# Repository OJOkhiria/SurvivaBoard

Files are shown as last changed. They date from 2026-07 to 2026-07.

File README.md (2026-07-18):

# SurvivaBoard
A custom LoRa board equipped with an ESP32-S3-WROOM-1-N16R8, Ebyte E22-900M22S SX1262 radio, U.FL antenna, U-BLOX MAX M10S 00B GPS module, MMC5983MA magnetometer, BME688 environmental sensor, and a CR2013-MI2120 display driven by an ILI9341 controller. **DISCLAIMER: AI was lightly used to ensure best practices were followed and to speed up research on parts.**

View demos here!: https://drive.google.com/drive/folders/1J8KjE548HSbNNH2rjGCe2-w3qN4_1LWy?dmr=1&ec=wgc-drive-%5Bmodule%5D-goto 

(drive is currently empty because board isn't built yet)

You can view the PCB on your own with https://kicanvas.org/

# Power
Because the board uses a variety of sensors, a GPS, a radio, and other noisy components, I created two separate 3.3V power rails for devices with different noise tolerances. 5V power first comes in from the USB-C receptacle and is stepped down with a fixed-output 3.3V buck converter (ap63203wu-7). To avoid surging, there are TVS diodes on the USB power lines and the D+/D- data lines, and a polyfuse on the power line immediately before the buck converter. The raw output from the buck converter will be used for the ESP32, Ebyte E22-900M22S, and ILI9341. This output also goes through a ferrite bead and an LDO (tlv75533pdrvr) converter to further reduce noise for sensors and other peripherals.

# Subsystems
**ESP32-S3-WROOM-1-N16R8:** Serves as the controller for the entire board. Has a built-in antenna for WiFi and Bluetooth interfacing and communicates with the other various subsystems with UART, SPI, and I²C. It's equipped with an external reset button and plenty of bulk decoupling using 0.1μF and 10μF capacitors.

**U-Blox MAX M10S 00B:** A GPS/GNSS module that will be used to gather data on the board's location and communicate with the ESP32 via UART. Equipped with a TPD1E05U06DPY ESD protection diode; 10μF, 1μF, and 0.1μF decoupling capacitors; and an external coax connector for an active patch antenna (the Quectel YCGO011AA). 

**Ebyte E22-900M22S:** A LoRa module built on the SX1262 transceiver. Originally, I was going to use a bare SX1262, but I chose to go with the Ebyte module to avoid having to build an entire RF front end from scratch. Has an onboard coax connector for an antenna, which will be connected to the FXP290.07.0100A. Communicates with the ESP32 via SPI, and may be used for Meshtastic integration.

**MMC5983MA:** The magnetometer of the board. It will provide heading information to provide the board with a built-in compass. Communicates with the ESP32 using I²C, and has 1μF and 10μF decoupling capacitors.

**BME688:** An environmental sensor that measures temperature, humidity, barometric pressure, and VOC gases. It can generate IAQ (indoor air quality) and also has integrated artificial intelligence, which will be trained to recognize certain odors/gas signatures. Has 0.1μF and 1μF decoupling capacitors and communicates with the ESP32 using I²C.

**ILI9341:** This will be used to display all the information the board gathers, and potentially for users to use Meshtastic. Has an SD card interface for any fonts or other things, and a PWM backlight control. Has 0.1μF and 10μF decoupling capacitors and communicates with the ESP32 using SPI.

# PCB Design
I went with an 80mm by 120mm rectangular 4-layer with 5mm radius filleted edges, with the following designations:
* Layer 1: Signals and USB power processing
* Layer 2: Solid ground plane (with some unfilled areas for antenna clearance)
* Layer 3: Bulk power distribution
* Layer 4: Extra signals

The subsystems are separated and clustered with their respective components to shorten routes and minimize noise interference, and some of these areas are demarcated with stitching vias. The display sits at the head of the board with the Ebyte module, I²C sensors, and a logo immediately underneath. Near the equator and to the left of the board sits the ESP32, with the antenna facing the board's edge and ~9mm of copper-free clearance on both sides of the antenna. On the right is a 25x25mm copper-free clearance zone to (hopefully) mount the Quectel YCGO011AA. In the bottom left is the MAX M10S with a U.FL coax connector, and in the bottom right is the USB-C receptacle and the power systems.

# Bill of Materials

|Reference|Qty|Value|DNP|Exclude from BOM|Exclude from Board|Footprint|Datasheet|
|---|---|---|---|---|---|---|---|
|AE1|1|Antenna| | | | | |
|C6,C9,C12,C15,C19,C23,C25,C27,C29 | 9 | 0.1uF | | | |Capacitor_SMD:C_0603_1608Metric_Pad1.08x0.95mm_HandSolder|
|C7,C13,C22,C26,C28,C30 | 6 | 10uF | | | |Capacitor_SMD:C_0805_2012Metric_Pad1.18x1.45mm_HandSolder| |
|C10,C11 | 2 | 22uF | | | | Capacitor_SMD:C_1206_3216Metric_Pad1.33x1.80mm_HandSolder | |
|C14 | 1 | 2.2uF | | | | Capacitor_SMD:C_0603_1608Metric_Pad1.08x0.95mm_HandSolder | |
|C16,C18,C20 | 3 | 1uF | | | |Capacitor_SMD:C_0603_1608Metric_Pad1.08x0.95mm_HandSolder | |
|C21 | 1 | 47pF | | | | Capacitor_SMD:C_0603_1608Metric_Pad1.08x0.95mm_HandSolder | |
|C24 | 1 | 4.7uF | | | | Capacitor_SMD:C_0603_1608Metric_Pad1.08x0.95mm_HandSolder | |
| D1 | 1 | D_TVS | | | | Diode_SMD:D_SOD-123F| |
|F1 | 1 | Polyfuse | | | | Fuse:Fuse_2920_7451Metric_Pad2.10x5.45mm_HandSolder | |
|FB1 | 1 | FerriteBead | | | | Ferrite_SMD:BEADC1608X95N | |
|IC1 | 1 | E22-900M22S | | | | ebyte:E22-900M22S | |
| J1 | 1 | USB_C_Receptacle_USB2.0_14P | | | | Connector_USB:USB_C_Receptacle_GCT_USB4105-xxA_16P_TopMnt_Horizontal | https://www.usb.org/sites/default/files/documents/usb_type-c.zip|
| J2 | 1 | Conn_Coaxial | | | | Connector_Coaxial:U.FL_Hirose_U.FL-R-SMT-1_Vertical | |
| L2 | 1 | 3.9uH | | | | Inductor_SMD:L_Sunlord_MWSA0402S | |
| L3 | 1 | 27nH | | | | Inductor_SMD:L_0603_1608Metric_Pad1.05x0.95mm_HandSolder | |
| R1,R2 | 2 | 5.1k | | | | Resistor_SMD:R_0603_1608Metric_Pad0.98x0.95mm_HandSolder | |
| R3,R4 | 2 | 4.7k | | | | Resistor_SMD:R_0603_1608Metric_Pad0.98x0.95mm_HandSolder | |
| R5 | 1 | 10k | | | | Resistor_SMD:R_0603_1608Metric_Pad0.98x0.95mm_HandSolder | |
| SW1 | 1 | SW_Push | | | | Tactile_Switch:SW_TS04-66-55-BK-160-SMT | |
| U1 | 1 | ESP32-S3-WROOM-1 | | | | ESP32-S3-WROOM-1-N16R8:ESP32S3WROOM1N8R2 | https://www.espressif.com/sites/default/files/documentation/esp32-s3-wroom-1_wroom-1u_datasheet_en.pdf|
| U2 | 1 | TPD2EUSB30A | | | | USB_ESD:SOTFL35P100X50-3N |http://www.ti.com/lit/ds/symlink/tpd2eusb30a.pdf|
| U3 | 1 | AP63203WU | | | | Buck_Converter:SOIC_05WU-7_DIO-M |https://www.diodes.com/assets/Datasheets/AP63200-AP63201-AP63203-AP63205.pdf|
| U5 | 1 | MAX-M10S | | | | U-BLOX MAX-M10S:XCVR_MAX-M10S-00B | https://content.u-blox.com/sites/default/files/MAX-M10S_DataSheet_UBX-20035208.pdf|
| U6 | 1 | MMC5983MA | | | | MMC5983MA:MMC5983MA_MEM | |
| U7 | 1 | BME688 | | | | BME688:IC_BME688 | |
| U8 | 1 | TLV75533PDRV | | | | LDO:SOT95P280X145-5N |http://www.ti.com/lit/ds/symlink/tlv755p.pdf|
| U9 | 1 | TPD1E05U06DPY | | | | GPS_ESD:DIO_TPD1E05U06DPYR | https://www.ti.com/lit/ds/symlink/tpd1e05u06.pdf|
| U10 | 1 | CR2013-MI2120 | | | | ILI9341:CR2013-MI2120 | http://pan.baidu.com/s/11Y990|

Screenshot 2026-07-08 at 11 11 59 PM

Screenshot 2026-07-11 at 3 25 43 PM

Screenshot 2026-07-09 at 12 09 27 AM

Screenshot 2026-07-13 at 2 32 15 PM

Screenshot 2026-07-13 at 2 34 44 PM

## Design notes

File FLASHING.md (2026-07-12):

# Flashing SurvivaBoard

The project targets an ESP32-S3-WROOM-1-N16R8 with 16 MB of flash. Firmware
logs use USB Serial/JTAG so UART0 remains available to the MAX-M10S GNSS module.

## Build

```sh
pio run
```

The resulting artifacts are written to:

```text
.pio/build/esp32-s3-devkitc-1-n16r8v/
```

## Flash

Connect the board's USB-C port, then run:

```sh
pio run --target upload
```

If PlatformIO cannot select the serial device automatically, pass the port:

```sh
pio run --target upload --upload-port /dev/cu.usbmodemXXXX
```

On first bring-up, hold the ESP32 boot strap low while resetting the module if
the ROM bootloader does not enter download mode automatically.

The current schematic does not expose GPIO0 as a dedicated BOOT button or test
pad. If the first upload does not start automatically, temporarily pull the
ESP32-S3 module's GPIO0 pad to GND while resetting EN. Add an accessible BOOT
test pad or button in the next PCB revision.

## Monitor

```sh
pio device monitor --baud 115200
```

Expected initial logs report the shared bus bring-up and the availability of
the ILI9341 interface, E22 radio interface, MAX-M10S UART, BME688, and
MMC5983MA.

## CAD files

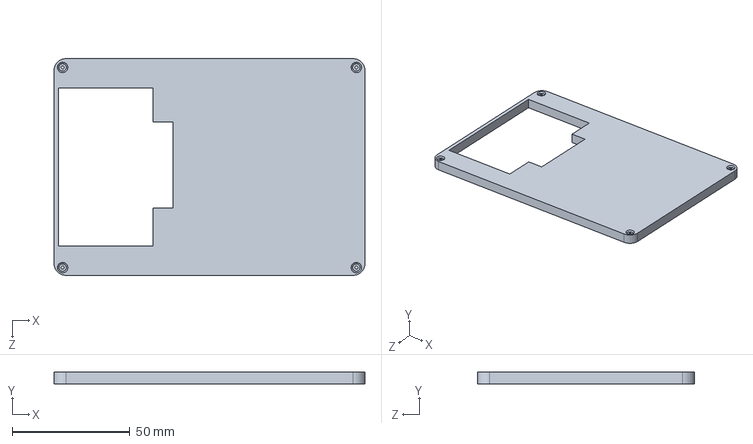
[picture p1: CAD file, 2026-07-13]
CAD Files/SurvivaBoard Case(2).SLDPRT
132.0 x 5.00 x 92.0 mm

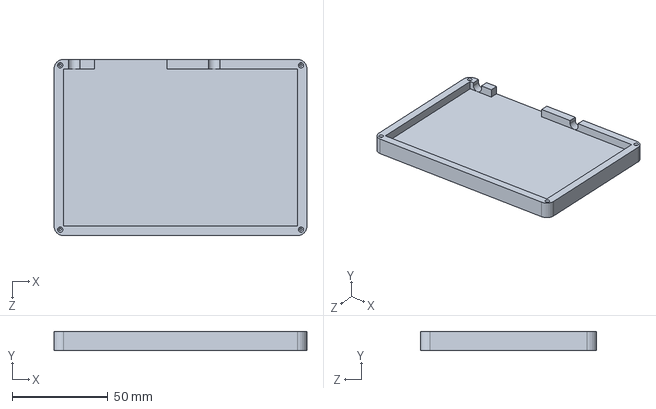
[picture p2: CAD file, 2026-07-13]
CAD Files/SurvivaBoard Case(1).SLDPRT
132.0 x 10.0 x 92.0 mm

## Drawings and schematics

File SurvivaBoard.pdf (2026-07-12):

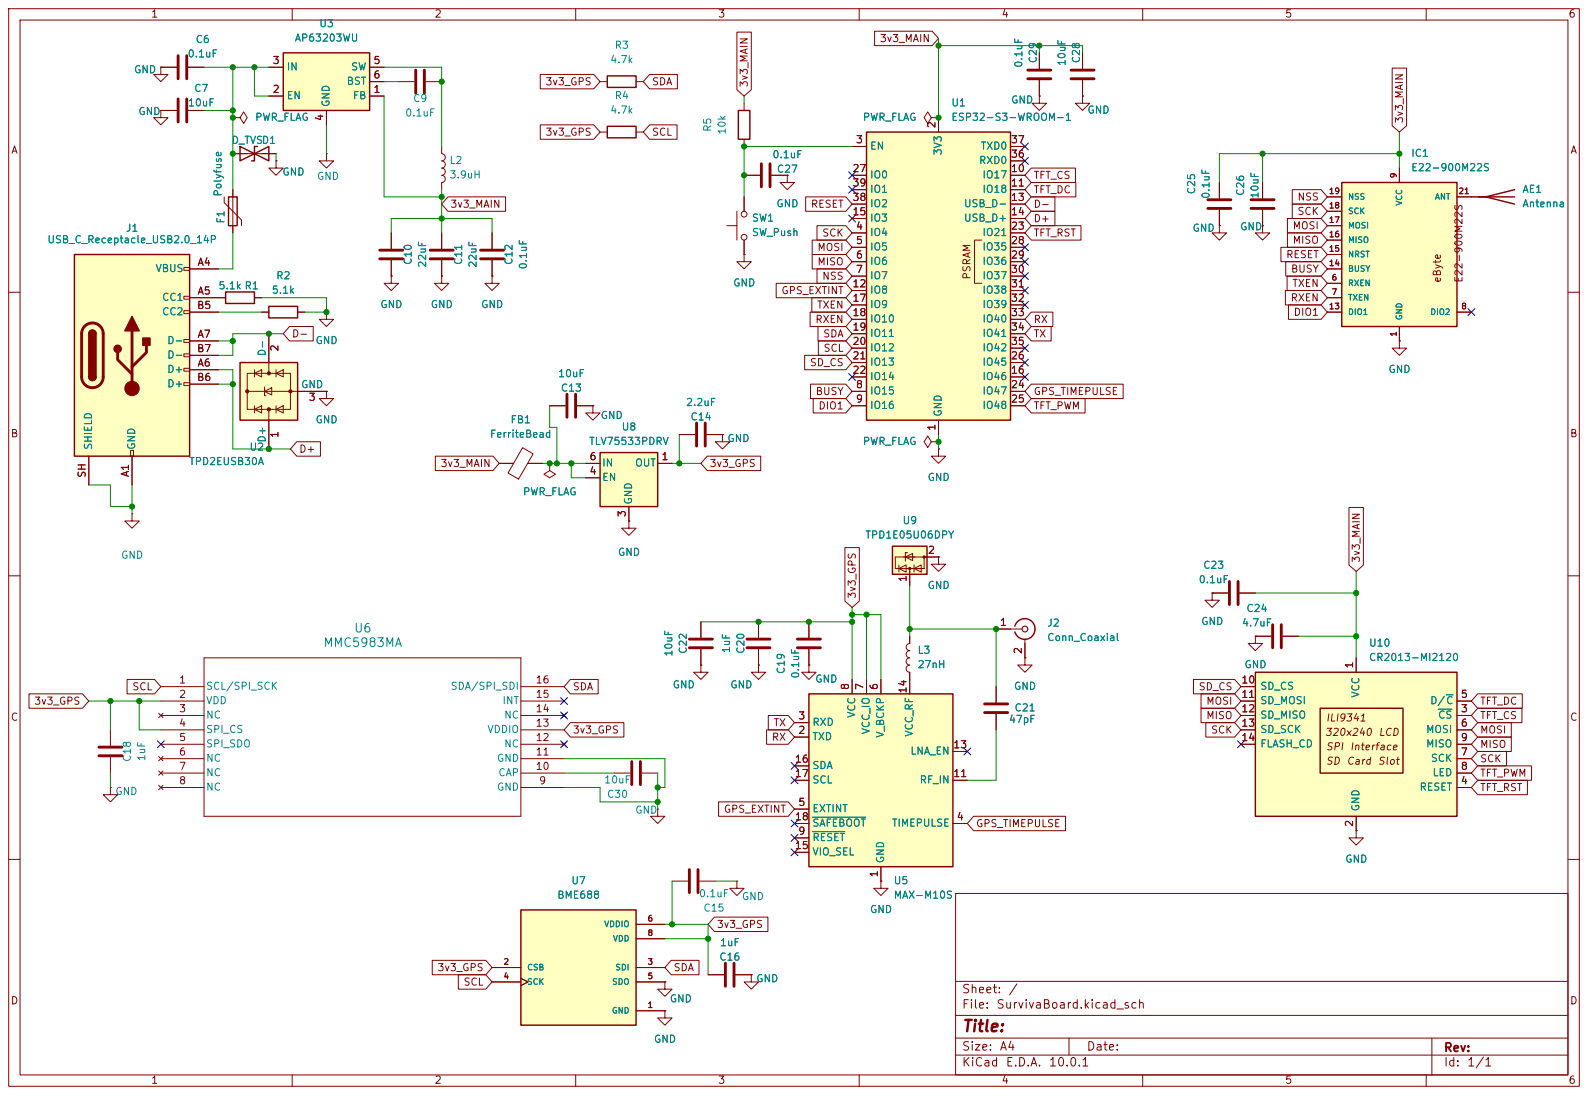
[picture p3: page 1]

9 DIO1 13 BUSY 14 NRST 15 MISO 16 MOSI 17

1 GND
SPI Interface SD Card Slot 320x240 LCD VCC

Size: A4 | Rev:
KiCad E.D.A. 10.0.1 | Id: 1/1

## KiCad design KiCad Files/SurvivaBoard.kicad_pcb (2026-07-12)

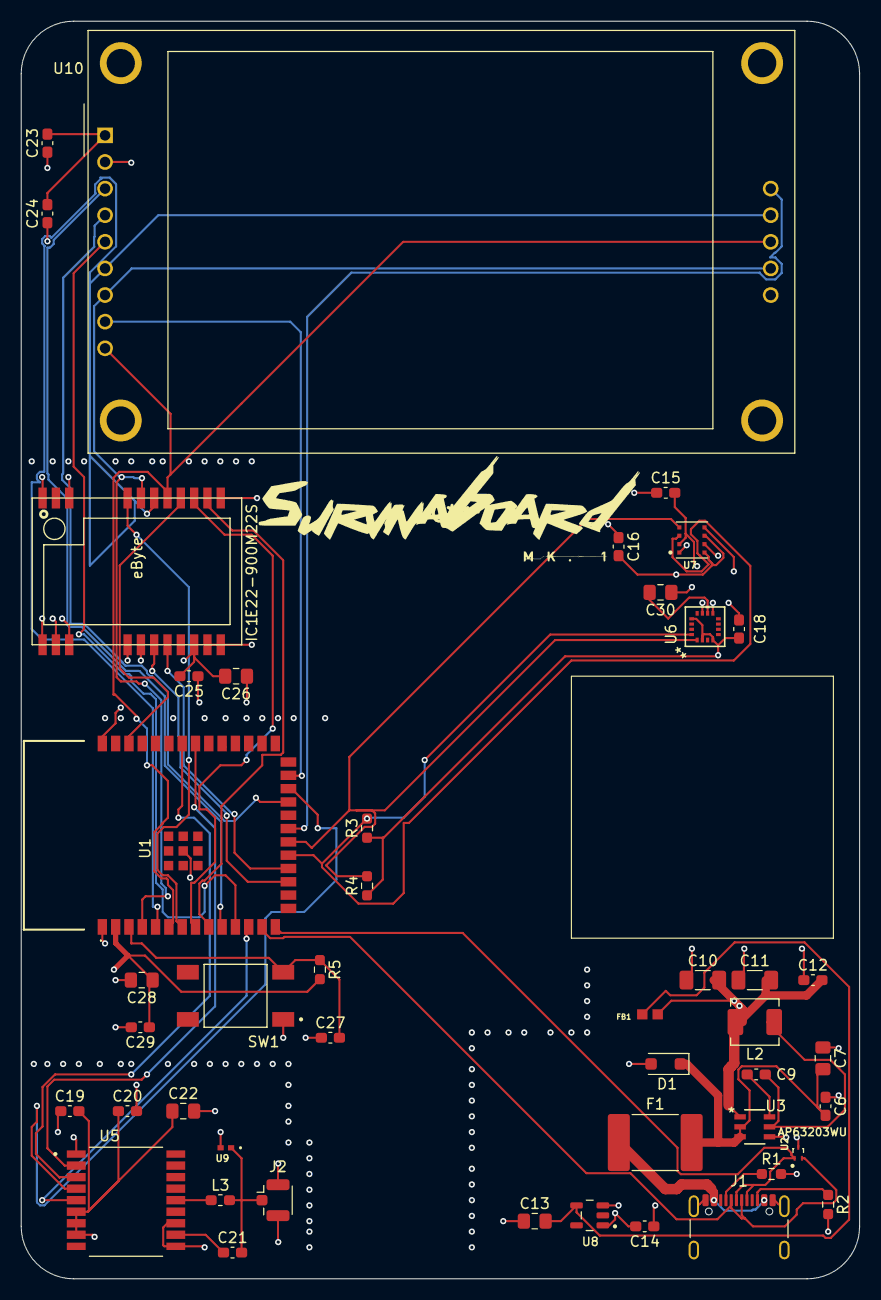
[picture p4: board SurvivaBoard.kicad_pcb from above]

Board: 4 copper layers, 80.0 x 120.0 mm, 46 parts (0 on the bottom side), 37 nets.

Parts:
C6, C9, C12, C15, C19, C23, C25, C27, C29: 0.1uF; C_0603_1608Metric_Pad1.08x0.95mm_HandSolder
C7, C13, C22, C26, C28, C30: 10uF; C_0805_2012Metric_Pad1.18x1.45mm_HandSolder
C10, C11: 22uF; C_1206_3216Metric_Pad1.33x1.80mm_HandSolder
C14: 2.2uF; C_0603_1608Metric_Pad1.08x0.95mm_HandSolder
C16, C18, C20: 1uF; C_0603_1608Metric_Pad1.08x0.95mm_HandSolder
C21: 47pF; C_0603_1608Metric_Pad1.08x0.95mm_HandSolder
C24: 4.7uF; C_0603_1608Metric_Pad1.08x0.95mm_HandSolder
D1: D_TVS; D_SOD-123F
F1: Polyfuse; Fuse_2920_7451Metric_Pad2.10x5.45mm_HandSolder
FB1: FerriteBead; BEADC1608X95N
IC1: E22-900M22S
J1: USB_C_Receptacle_USB2.0_14P; USB_C_Receptacle_GCT_USB4105-xx-A_16P_TopMnt_Horizontal
J2: Conn_Coaxial; U.FL_Hirose_U.FL-R-SMT-1_Vertical
L2: 3.9uH; L_Sunlord_MWSA0402S
L3: 27nH; L_0603_1608Metric_Pad1.05x0.95mm_HandSolder
R1, R2: 5.1k; R_0603_1608Metric_Pad0.98x0.95mm_HandSolder
R3, R4: 4.7k; R_0603_1608Metric_Pad0.98x0.95mm_HandSolder
R5: 10k; R_0603_1608Metric_Pad0.98x0.95mm_HandSolder
SW1: SW_Push; SW_TS04-66-55-BK-160-SMT
U1: ESP32-S3-WROOM-1; ESP32S3WROOM1N8R2
U2: TPD2EUSB30A; SOTFL35P100X50-3N
U3: AP63203WU; SOIC_05WU-7_DIO-M
U5: MAX-M10S; XCVR_MAX-M10S-00B
U6: MMC5983MA; MMC5983MA_MEM
U7: BME688; IC_BME688
U8: TLV75533PDRV; SOT95P280X145-5N
U9: TPD1E05U06DPY; DIO_TPD1E05U06DPYR
U10: CR2013-MI2120

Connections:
3v3_GPS: C14.2, C15.2, C16.2, C18.2, C19.2, C20.1, C22.1, R3.1, R4.1, U5.6 (V_BCKP), U5.7 (VCC_IO), U5.8 (VCC), U6.2 (VDD), U6.4 (SPI_CS), U6.13 (VDDIO), U7.2 (CSB), U7.6 (VDDIO), U7.8 (VDD), U8.1 (OUT)
3v3_MAIN: C10.2, C11.2, C12.2, C23.2, C24.2, C25.2, C26.2, C28.1, C29.1, FB1.1, IC1.9 (VCC), L2.2, R5.2, U1.2 (3V3), U3.1 (FB), U10.1 (VCC)
BUSY: IC1.14 (BUSY), U1.8 (IO15)
D+: J1.A6 (D+), J1.B6 (D+), U1.14 (USB_D+), U2.1 (D+)
D-: J1.A7 (D-), J1.B7 (D-), U1.13 (USB_D-), U2.2 (D-)
DIO1: IC1.13 (DIO1), U1.9 (IO16)
GND: C6.1, C7.1, C10.1, C11.1, C12.1, C13.1, C14.1, C15.1, C16.1, C18.1, C19.1, C20.2, C22.2, C23.1, C24.1, C25.1, C26.1, C27.1, C28.2, C29.2, C30.1, D1.2 (A2), IC1.1 (GND), IC1.2 (GND), IC1.3 (GND), IC1.4 (GND), IC1.5 (GND), IC1.10 (GND), IC1.11 (GND), IC1.12 (GND), IC1.20 (GND), IC1.22 (GND), J1.A1 (GND), J1.A12 (GND), J1.B1 (GND), J1.B12 (GND), J1.SH (SHIELD), J2.2 (Ext), R1.2, R2.2, SW1.1, U1.1 (GND), U1.40 (GND), U1.41 (GND), U2.3 (GND), U3.4 (GND), U5.1 (GND), U5.10 (GND), U5.12 (GND), U6.9 (GND), U6.11 (GND), U7.1 (GND), U7.5 (SDO), U7.7 (GND), U8.3 (GND), U9.2 (GND), U10.2 (GND)
GPS_EXTINT: U1.12 (IO8), U5.5 (EXTINT)
GPS_TIMEPULSE: U1.24 (IO47), U5.4 (TIMEPULSE)
MISO: IC1.16 (MISO), U1.6 (IO6), U10.9 (MISO), U10.12 (SD_MISO)
MOSI: IC1.17 (MOSI), U1.5 (IO5), U10.6 (MOSI), U10.11 (SD_MOSI)
NSS: IC1.19 (NSS), U1.7 (IO7)
unnamed: C6.2, C7.2, D1.1 (A1), F1.2, U3.2 (EN), U3.3 (IN)
unnamed: F1.1, J1.A4 (VBUS), J1.A9 (VBUS), J1.B4 (VBUS), J1.B9 (VBUS)
unnamed: J1.A5 (CC1), R1.1
unnamed: J1.B5 (CC2), R2.1
unnamed: C21.2, J2.1 (In), L3.2, U9.1 (I/O)
unnamed: C27.2, R5.1, SW1.2, U1.3 (EN)
unnamed: C9.1, U3.6 (BST)
unnamed: C9.2, L2.1, U3.5 (SW)
unnamed: C21.1, U5.11 (RF_IN)
unnamed: L3.1, U5.14 (VCC_RF)
unnamed: C30.2, U6.10 (CAP)
unnamed: C13.2, FB1.2, U8.4 (EN)
RESET: IC1.15 (NRST), U1.38 (IO2)
RX: U1.33 (IO40), U5.2 (TXD)
RXEN: IC1.7 (TXEN), U1.18 (IO10)
SCK: IC1.18 (SCK), U1.4 (IO4), U10.7 (SCK), U10.13 (SD_SCK)
SCL: R4.2, U1.20 (IO12), U6.1 (SCL/SPI_SCK), U7.4 (SCK)
SDA: R3.2, U1.19 (IO11), U6.16 (SDA/SPI_SDI), U7.3 (SDI)
SD_CS: U1.21 (IO13), U10.10 (SD_CS)
TFT_CS: U1.10 (IO17), U10.3 (~CS)
TFT_DC: U1.11 (IO18), U10.5 (D/~C)
TFT_PWM: U1.25 (IO48), U10.8 (LED)
TFT_RST: U1.23 (IO21), U10.4 (RESET)
TX: U1.34 (IO41), U5.3 (RXD)
TXEN: IC1.6 (RXEN), U1.17 (IO9)

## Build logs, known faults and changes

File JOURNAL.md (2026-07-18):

# 1
In this session, I worked on the full power system for SurvivaBoard. Because the board uses a variety of sensors, a GPS, a radio, and other noisy components, I created two separate 3.3V power rails for devices with different noise tolerances. 5V power first comes in from the USB-C receptacle and is stepped down with a fixed-output 3.3V buck converter. The raw output from the buck converter will be used for the ESP32, SX1262, and TFT display. This output also goes through a ferrite bead and an LDO converter to further reduce noise for sensors and other peripherals.



# 2
In this session, I wired all the subsystems for SurvivaBoard and tweaked my power system a bit. In summary, I:

- Added a polyfuse and TVS diode to my USB power system to avoid surging
- Added an ESD to the D+ and D- pins before connecting to the ESP32
- Switched from a bare SX1262 to the Ebyte E22-900M22S to avoid having to create an entire RF front end from scratch
- Changed to a simpler TFT module to keep the board hierarchy centered around the ESP32
- Selected and wired which GPIO pins to use for peripherals (after researching for half an hour which ones I could and couldn’t use)
- Added a reset button to the ESP32
- Added proper local decoupling to each IC



# 3
In this session, I researched the proper footprints for all my components and assigned them before moving on to PCB routing.



# 4
In this session, I plotted all the footprints into the PCB editor and got to routing. I went with a 80mmx120mm 4 layer board. The first and bottom layers are for general signal connections and decoupling, the second layer is a solid ground plane, and the third is for bulk power distribution. The different components are also grouped in a certain way to minimize noise and interference while avoiding winding/convoluted traces. 



# 5
In this session, I fixed all the errors on the PCB, made the routing a little more organized, added clearance around the various antennae, added stitching vias, made and added a logo, and changed a few components.

For the environmental sensor, I switched from the BME680 to the BME688 for its AI capabilities, and for the magnetometer, I switched from the LIS2MDLTR to the MMC5983MA because the LIS2MDL was way too hard to source. I also tweaked the inductance of the buck converter to 3.9uH instead of 2.2, and I adjusted the track thickness by component to account for power needs.



# 6
**FINALLY DONE 🥹**

In this session, I wrote the firmware for flashing onto the ESP32. This was honestly the most confusing part of the project. I built it in VS Code with the PlatformIO and ESP-IDF extensions for project management and framework. I also used FreeRTOS with modular drivers to make future edits easier to make. The architecture is based on multiple layers of hardware abstraction and interconnection. For example, programs for sensors will never interface directly with GPIO pins and i2c protocol, instead just sending a read/write request. In addition to the component and communication buses, I also built a display protocol for initializing the board, scanning for sensor presence, gathering data, and updating it in real-time on the screen about twice every second. All of this was wrapped into a flashable bin, meaning **SURVIVABOARD IS READY TO GO!**



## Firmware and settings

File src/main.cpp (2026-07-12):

#include "esp_log.h"
#include "freertos/FreeRTOS.h"
#include "freertos/task.h"

#include "bme688.hpp"
#include "display.hpp"
#include "gps.hpp"
#include "hal_i2c.hpp"
#include "hal_spi.hpp"
#include "hal_uart.hpp"
#include "lora.hpp"
#include "mmc5983ma.hpp"

namespace
{
constexpr char TAG[] = "survivaboard";
void logInitialization(const char* name, const esp_err_t result)
{
    if (result == ESP_OK)
    {
        ESP_LOGI(TAG, "%s ready", name);
        return;
    }

    ESP_LOGW(TAG, "%s unavailable: %s", name, esp_err_to_name(result));
}
}

extern "C" void app_main()
{
    ESP_ERROR_CHECK(HAL::I2C::init());
    ESP_ERROR_CHECK(HAL::SPI::init());

    Display display;
    LoRa lora;
    GPS gps;
    BME688 environment;
    MMC5983MA magnetometer;

    logInitialization("ILI9341 SPI interface", display.begin());
    logInitialization("E22 LoRa interface", lora.begin());
    logInitialization("MAX-M10S UART", gps.begin());
    logInitialization("BME688", environment.begin());
    logInitialization("MMC5983MA", magnetometer.begin());

    ESP_LOGI(TAG, "SurvivaBoard bring-up complete");

    while (true)
    {
        vTaskDelay(pdMS_TO_TICKS(1000));    }

    }

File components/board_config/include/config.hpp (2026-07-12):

#pragma once

#include <cstdint>

namespace Settings
{
constexpr uint32_t I2C_SPEED = 400000;
constexpr uint32_t SPI_SPEED_DISPLAY = 40000000;
constexpr uint32_t SPI_SPEED_LORA = 8000000;
constexpr uint32_t GPS_BAUD = 9600;
constexpr uint32_t GPS_UART_RX_BUFFER_SIZE = 2048;
constexpr uint32_t GPS_UART_TX_BUFFER_SIZE = 1024;
}  // namespace Settings

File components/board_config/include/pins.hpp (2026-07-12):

#pragma once

#include "driver/gpio.h"

namespace board::pins {

inline constexpr gpio_num_t spi_sck  = GPIO_NUM_4;
inline constexpr gpio_num_t spi_mosi = GPIO_NUM_5;
inline constexpr gpio_num_t spi_miso = GPIO_NUM_6;

inline constexpr gpio_num_t lora_reset = GPIO_NUM_3;
inline constexpr gpio_num_t lora_cs    = GPIO_NUM_7;
inline constexpr gpio_num_t gps_extint = GPIO_NUM_8;
inline constexpr gpio_num_t lora_txen  = GPIO_NUM_9;
inline constexpr gpio_num_t lora_rxen  = GPIO_NUM_10;

inline constexpr gpio_num_t i2c_sda = GPIO_NUM_11;
inline constexpr gpio_num_t i2c_scl = GPIO_NUM_12;
inline constexpr gpio_num_t sd_cs = GPIO_NUM_13;

inline constexpr gpio_num_t lora_busy = GPIO_NUM_15;
inline constexpr gpio_num_t lora_dio1 = GPIO_NUM_16;

inline constexpr gpio_num_t tft_cs  = GPIO_NUM_17;
inline constexpr gpio_num_t tft_dc  = GPIO_NUM_18;
inline constexpr gpio_num_t tft_rst = GPIO_NUM_21;
inline constexpr gpio_num_t mag_int = GPIO_NUM_38;

inline constexpr gpio_num_t gps_timepulse = GPIO_NUM_47;
inline constexpr gpio_num_t tft_pwm       = GPIO_NUM_48;

inline constexpr gpio_num_t gps_rx = GPIO_NUM_44; // ESP32 RX <- GPS TX
inline constexpr gpio_num_t gps_tx = GPIO_NUM_43; // ESP32 TX -> GPS RX

} // namespace board::pins

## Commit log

2026-07-11 Enhance README with detailed board description and power info
    Expanded the description of the SurvivaBoard and added a section on power management detailing the power rails and components used.
2026-07-11 Enhance README with subsystem details
    Added detailed descriptions for various subsystems including ESP32, GPS, LoRa, magnetometer, environmental sensor, and display.
2026-07-11 Enhance README with PCB design and BOM details
    Added PCB design and bill of materials sections to README.
2026-07-11 Update README with Bill of Materials
    Added a detailed Bill of Materials section with component references, quantities, values, and additional information.
2026-07-12 committed initial firmware files for the ESP32-S3-DevKitC-1-N16R8V board.
2026-07-12 Made headers for the board, buses, and config files. Added a new main.cpp file to replace the old main.c file. Updated platformio.ini to include the correct board and framework settings.
    [config.hpp, main.cpp, pins.hpp]
2026-07-12 Changed folder name
    [SurvivaBoard.kicad_pcb, SurvivaBoard.kicad_sch]
2026-07-12 Added finishing touches to prepare for flashing and added instructions
    [partitions.csv]
2026-07-18 Update README with demo and PCB design links
    Added links to demos and PCB design in README.
2026-07-18 Update README to remove PCB design link
    Removed outdated PCB design link from README.
2026-07-18 Update README with PCB and demo links
    Added links for PCB viewing and demo videos.
2026-07-18 Add journal entry for SurvivaBoard power system
    Documented the design and implementation of the power system for SurvivaBoard, detailing the use of separate power rails and noise reduction techniques.
2026-07-18 Update JOURNAL.md with SurvivaBoard development logs
    Documented the development progress of SurvivaBoard, detailing power system design, subsystem wiring, PCB routing, and firmware implementation.
